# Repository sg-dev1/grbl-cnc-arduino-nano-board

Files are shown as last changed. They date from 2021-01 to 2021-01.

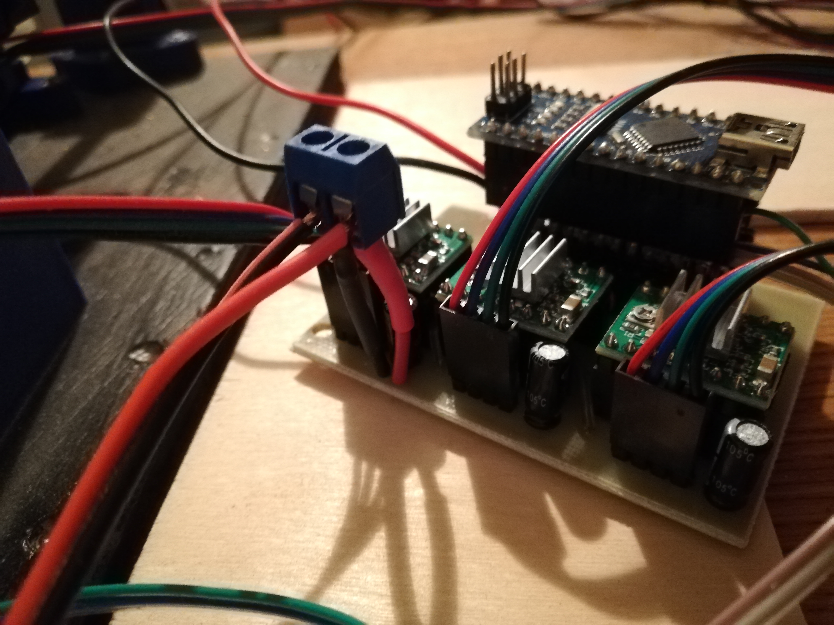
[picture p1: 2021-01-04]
pictures/4_motor_power_connector.jpg

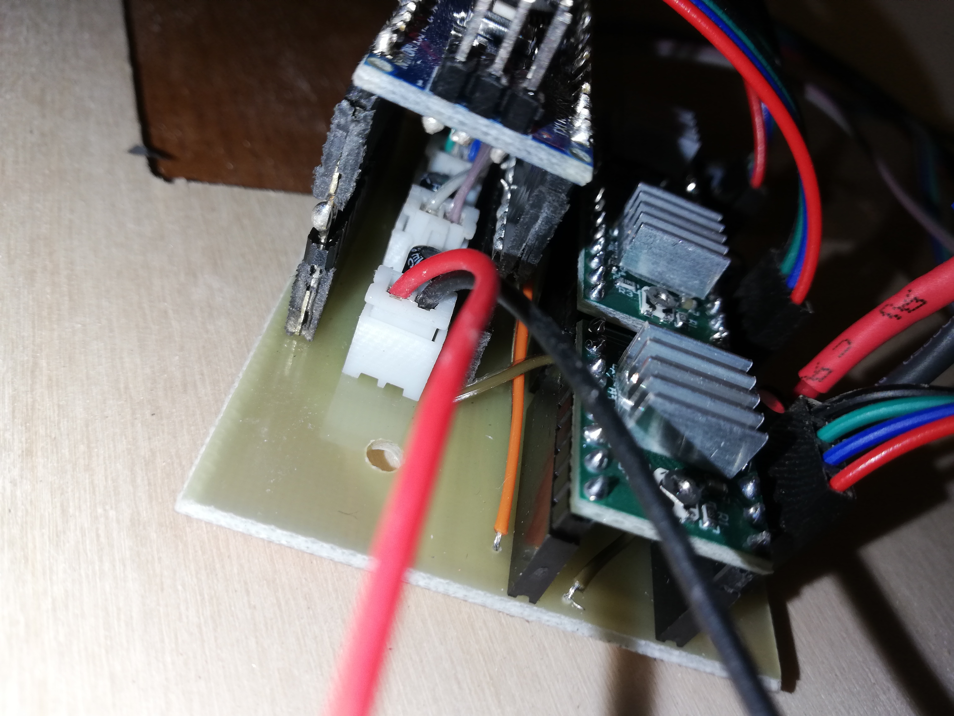
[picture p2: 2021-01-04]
pictures/3_probe_connector.jpg

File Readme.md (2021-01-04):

# Overview

This repository contains the schematics/ pcb layout for a GRBL control board.

The PCB layout is fit onto a 7x5 cm pcb.

# Description

Due to custom pin assignments a custom GRBL version needs to be used [1].

Components required:
 * 1 7x5 cm pcb
 * 1 Arduino Nano
 * 3 stepper drivers (A4988 or similar)
 * 3 100 uf capacitators used between VMOT and GNDMOT
 * 3 0.1 uf capacitators for endstops/ probe connector
 * Female headers to attach Arduino Nano and stepper drivers
 * 3 JST XH connectors for endstops and probe connector
 * Additional extension header to mount Arduino Nano a bit higher to have space for connectors (I soldered together male and female pin headers for that)
 * Screw terminal soldered onto some cables for power connector
 
 A 3d printable case can be found on thingiverse: https://www.thingiverse.com/thing:4709614

[1] https://github.com/sg-dev1/grbl

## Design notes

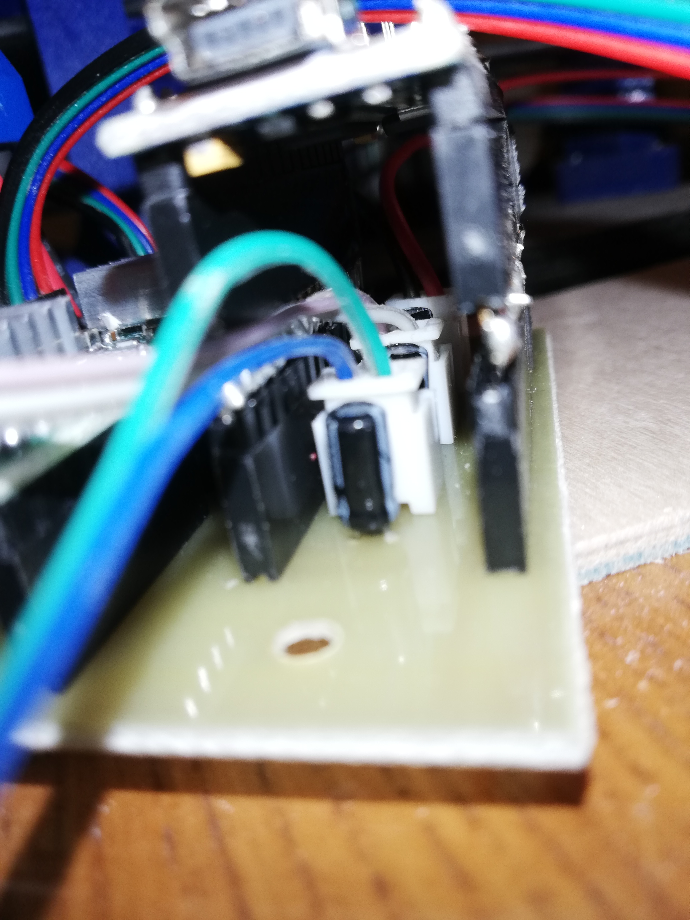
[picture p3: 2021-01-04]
pictures/2_endstop_connectors.jpg

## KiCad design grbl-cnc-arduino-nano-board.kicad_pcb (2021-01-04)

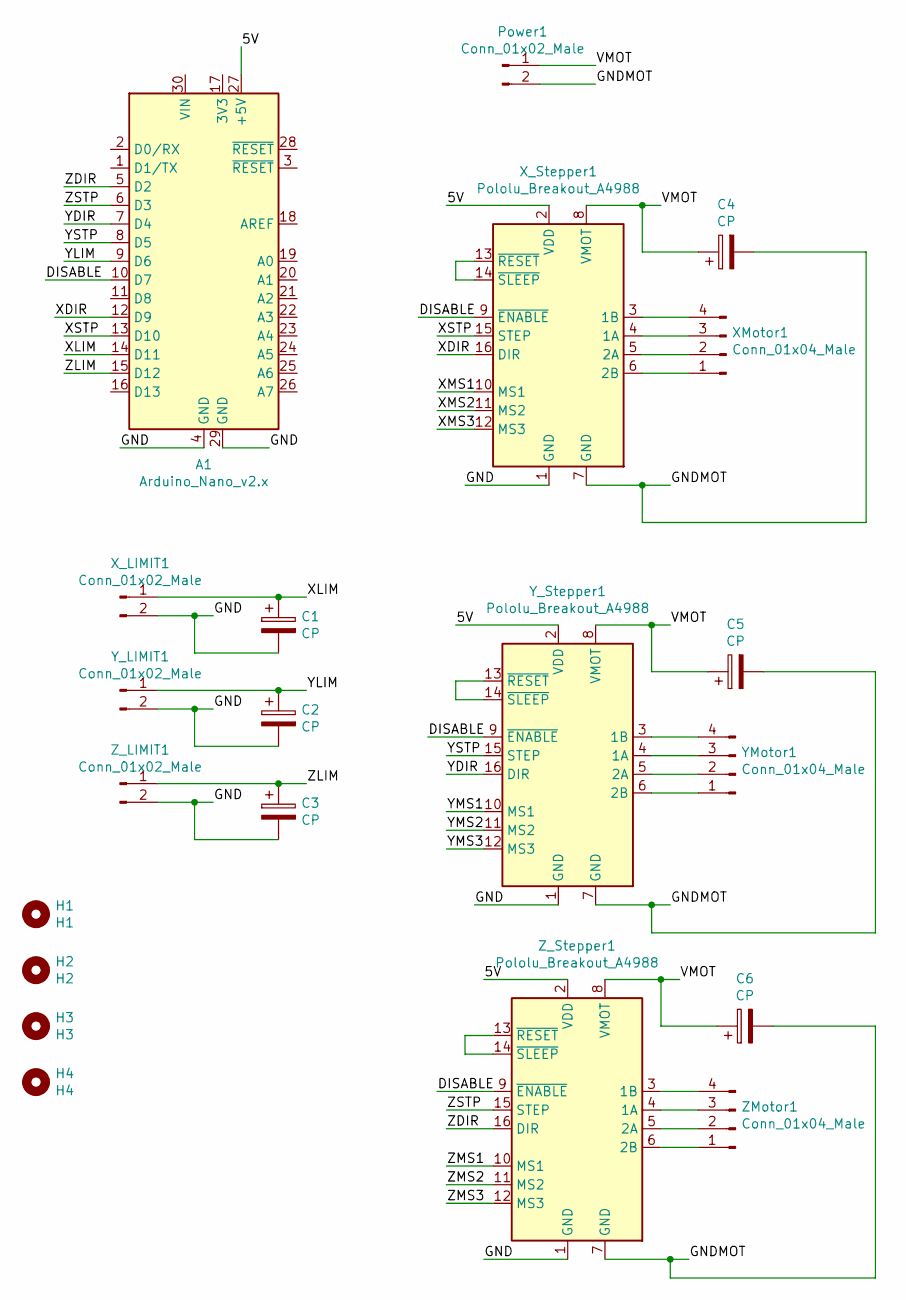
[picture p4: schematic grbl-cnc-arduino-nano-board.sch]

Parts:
A1: Arduino_Nano_v2.x; Arduino_Nano
C1, C2, C3, C4, C5, C6: CP; Capacitator_Radial_D5.0mm_P2.50mm
H1: H1; MountingHole_3.2mm_M3
H2: H2; MountingHole_3.2mm_M3
H3: H3; MountingHole_3.2mm_M3
H4: H4; MountingHole_3.2mm_M3
Power1: Conn_01x02_Male; PinHeader_1x02_P2.54mm_Vertical
XMotor1: Conn_01x04_Male; PinHeader_1x04_P2.54mm_Vertical
X_LIMIT1: Conn_01x02_Male; JST_XH_B2B-XH-A_1x02_P2.50mm_Vertical
X_Stepper1: Pololu_Breakout_A4988; Pololu_Breakout-16_15.2x20.3mm_custom
YMotor1: Conn_01x04_Male; PinHeader_1x04_P2.54mm_Vertical
Y_LIMIT1: Conn_01x02_Male; JST_XH_B2B-XH-A_1x02_P2.50mm_Vertical
Y_Stepper1: Pololu_Breakout_A4988; Pololu_Breakout-16_15.2x20.3mm_custom
ZMotor1: Conn_01x04_Male; PinHeader_1x04_P2.54mm_Vertical
Z_LIMIT1: Conn_01x02_Male; JST_XH_B2B-XH-A_1x02_P2.50mm_Vertical
Z_Stepper1: Pololu_Breakout_A4988; Pololu_Breakout-16_15.2x20.3mm_custom

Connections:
/5V: A1.27 (+5V), X_Stepper1.2 (VDD), Y_Stepper1.2 (VDD), Z_Stepper1.2 (VDD)
/DISABLE: A1.10 (D7), X_Stepper1.9 (~ENABLE), Y_Stepper1.9 (~ENABLE), Z_Stepper1.9 (~ENABLE)
/GND: A1.4 (GND), A1.29 (GND), C1.2, C2.2, C3.2, X_LIMIT1.2, X_Stepper1.1 (GND), Y_LIMIT1.2, Y_Stepper1.1 (GND), Z_LIMIT1.2, Z_Stepper1.1 (GND)
/GNDMOT: C4.2, C5.2, C6.2, Power1.2, X_Stepper1.7 (GND), Y_Stepper1.7 (GND), Z_Stepper1.7 (GND)
/VMOT: C4.1, C5.1, C6.1, Power1.1, X_Stepper1.8 (VMOT), Y_Stepper1.8 (VMOT), Z_Stepper1.8 (VMOT)
/XDIR: A1.12 (D9), X_Stepper1.16 (DIR)
/XLIM: A1.14 (D11), C1.1, X_LIMIT1.1
/XMS1: X_Stepper1.10 (MS1)
/XMS2: X_Stepper1.11 (MS2)
/XMS3: X_Stepper1.12 (MS3)
/XSTP: A1.13 (D10), X_Stepper1.15 (STEP)
/YDIR: A1.7 (D4), Y_Stepper1.16 (DIR)
/YLIM: A1.9 (D6), C2.1, Y_LIMIT1.1
/YMS1: Y_Stepper1.10 (MS1)
/YMS2: Y_Stepper1.11 (MS2)
/YMS3: Y_Stepper1.12 (MS3)
/YSTP: A1.8 (D5), Y_Stepper1.15 (STEP)
/ZDIR: A1.5 (D2), Z_Stepper1.16 (DIR)
/ZLIM: A1.15 (D12), C3.1, Z_LIMIT1.1
/ZMS1: Z_Stepper1.10 (MS1)
/ZMS2: Z_Stepper1.11 (MS2)
/ZMS3: Z_Stepper1.12 (MS3)
/ZSTP: A1.6 (D3), Z_Stepper1.15 (STEP)
unnamed: XMotor1.1, X_Stepper1.6 (2B)
unnamed: XMotor1.2, X_Stepper1.5 (2A)
unnamed: XMotor1.3, X_Stepper1.4 (1A)
unnamed: XMotor1.4, X_Stepper1.3 (1B)
unnamed: X_Stepper1.13 (~RESET), X_Stepper1.14 (~SLEEP)
unnamed: YMotor1.1, Y_Stepper1.6 (2B)
unnamed: YMotor1.2, Y_Stepper1.5 (2A)
unnamed: YMotor1.3, Y_Stepper1.4 (1A)
unnamed: YMotor1.4, Y_Stepper1.3 (1B)
unnamed: Y_Stepper1.13 (~RESET), Y_Stepper1.14 (~SLEEP)
unnamed: ZMotor1.1, Z_Stepper1.6 (2B)
unnamed: ZMotor1.2, Z_Stepper1.5 (2A)
unnamed: ZMotor1.3, Z_Stepper1.4 (1A)
unnamed: ZMotor1.4, Z_Stepper1.3 (1B)
unnamed: Z_Stepper1.13 (~RESET), Z_Stepper1.14 (~SLEEP)

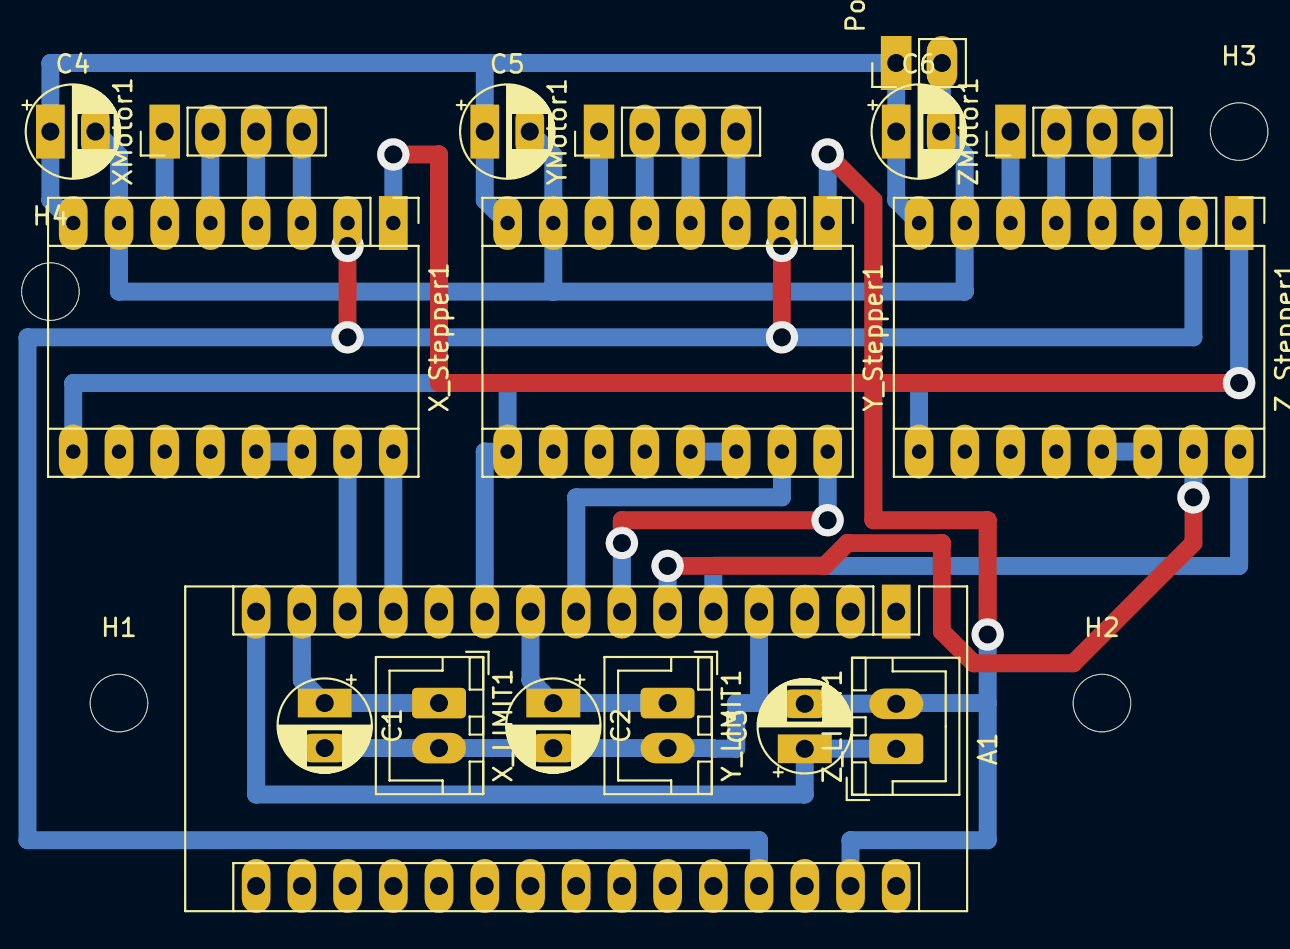
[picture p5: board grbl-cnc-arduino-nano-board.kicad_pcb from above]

Board: 2 copper layers, 21 parts (0 on the bottom side), 29 nets.
